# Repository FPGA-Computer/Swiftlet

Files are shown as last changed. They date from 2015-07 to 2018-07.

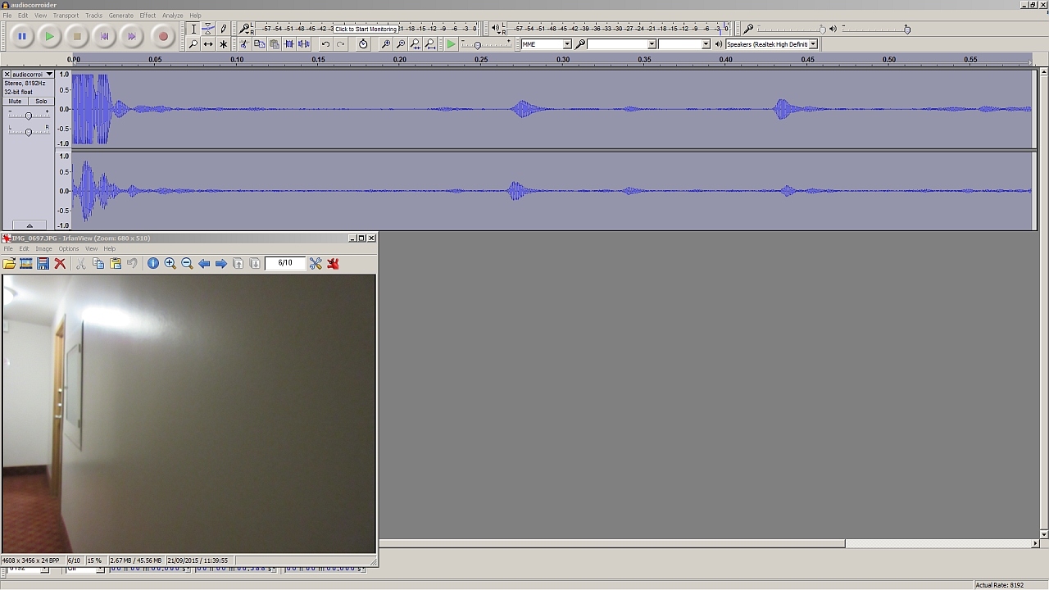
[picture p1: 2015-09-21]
Sonar Samples/corridor1.jpg

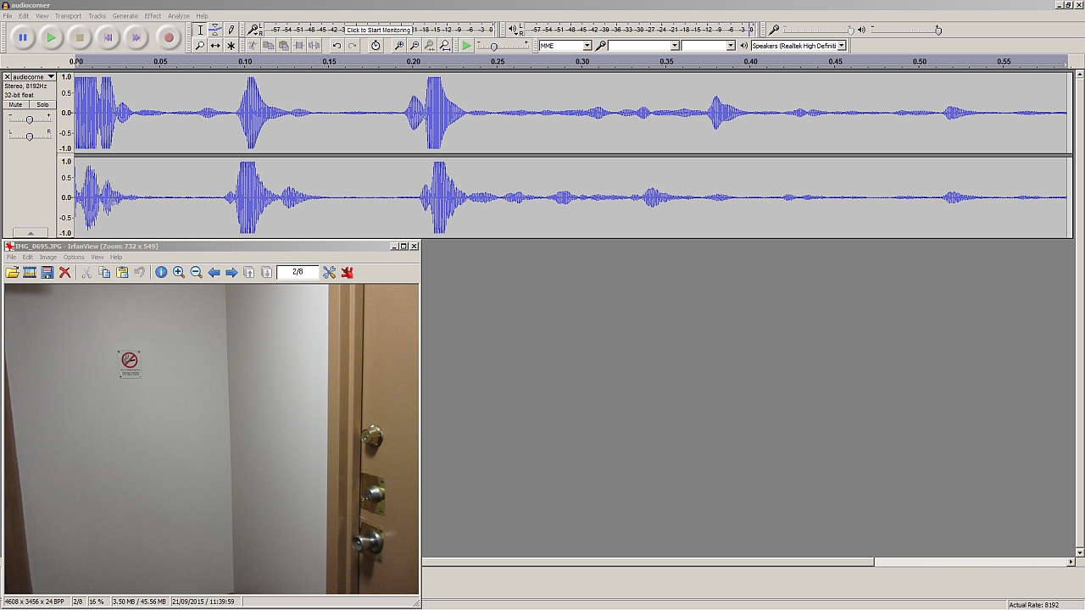
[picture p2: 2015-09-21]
Sonar Samples/Corner.jpg

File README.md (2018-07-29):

This is a Personal Sonar System or the Visually Impaired Person for HaD 2015 Contest Entry.

Ver 0.0 Rel 0/	
Initial PCB release - first layout/non-tested

Ver 0.0 Rel 0.1/	
Initial PCB release - bugs fixed (so far) against Rel 0.0

  Eagle PCB/ Eagle CAD files
  Sketch3D/  Sketch3D model
  LTSpice/   Linear Tech Spice Simulation analog file

Hackaday project page is at 
https://hw-by-design.blogspot.com/2018/07/project-swiftlet-sonar-for-visually.html

This work is licensed under a Creative Commons Attribution-
NonCommercial-ShareAlike 4.0 International License.

The full detail of this license is available at: 
http://creativecommons.org/licenses/by-nc-sa/4.0/

Please contact me via hackaday.io for commercial inquiries.

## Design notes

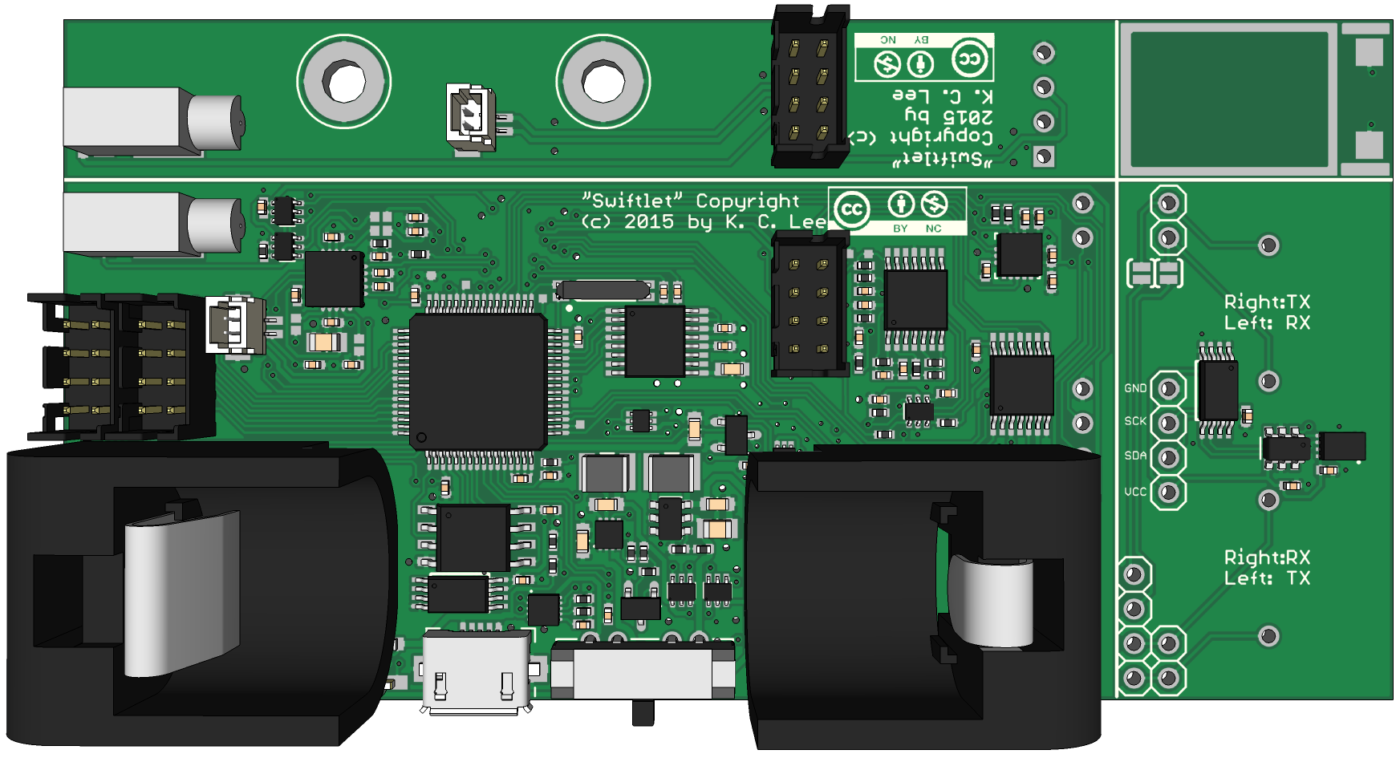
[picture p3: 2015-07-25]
Ver 0.0 Rel 0/Sketch3D/pcb-panel-top.png

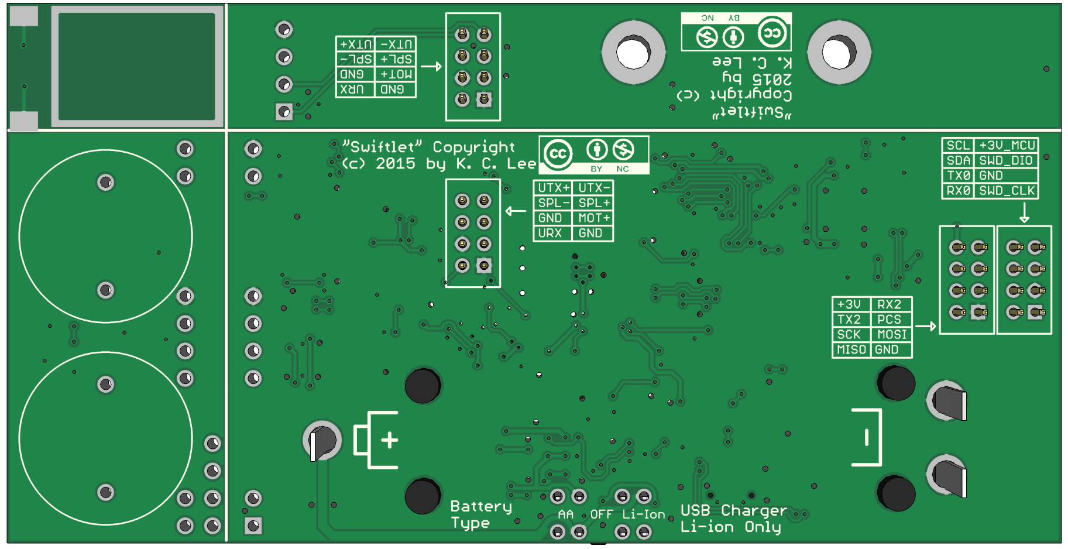
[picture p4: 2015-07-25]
Ver 0.0 Rel 0/Sketch3D/pcb-panel-bot.png

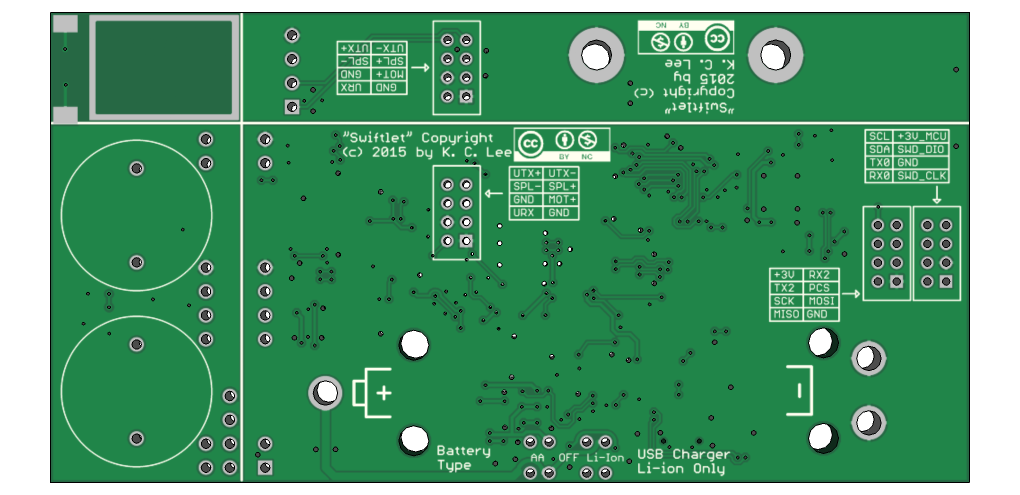
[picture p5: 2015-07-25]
Ver 0.0 Rel 0/Eagle PCB/''Swiftlet'' Sonar for the Visually Impaired Ver 0.0 Rel 0 - Bare PCB Bot.png

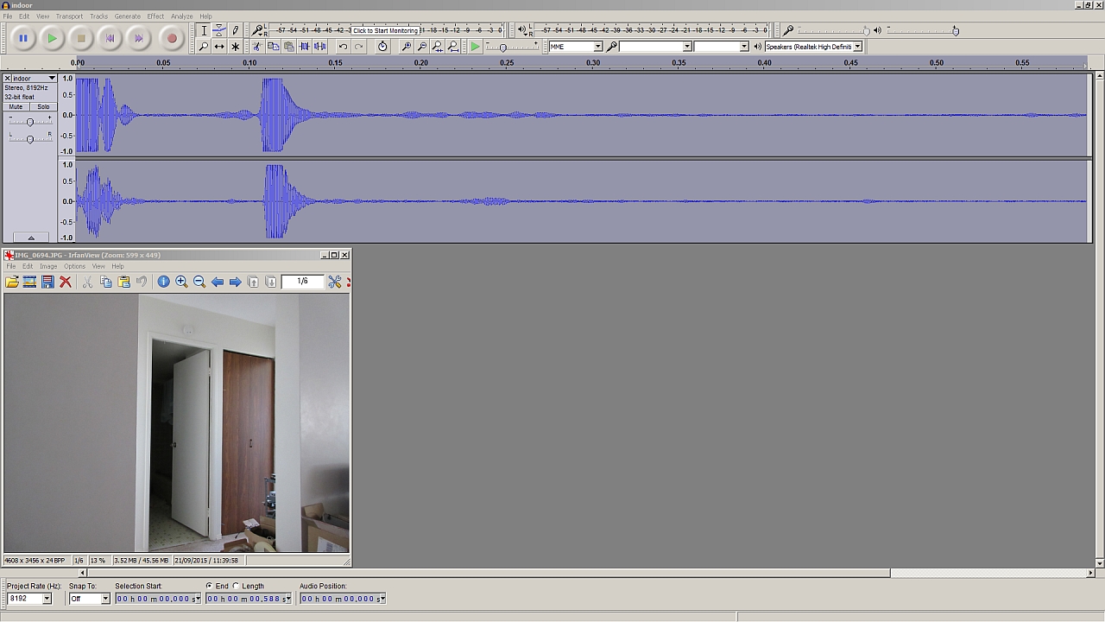
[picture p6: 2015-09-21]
Sonar Samples/indoor.jpg

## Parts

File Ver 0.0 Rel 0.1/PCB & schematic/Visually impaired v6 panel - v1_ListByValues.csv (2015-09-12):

Qty | Value | Part Num | Package | Parts
2 |  | * | 1X02 | J7, J8
2 |  | * | 1X04R | J6, J9
2 |  | * | SJ_2S-NO | SJ1, SJ2
1 |  | DX: SKU134132 | USB-AB-MICRO-SMD_V03_SF | J1
21 | 0.1uF | STOCK: DK 587-1227-1-ND | CAPC1005X60N | C3, C5, C6, C7, C9, C11, C16, C24, C31, C34, C35, C36, C38, C39, C42, C43, C44, C46, C48, C49, C50
1 | 0R | DK: 311-0.0JRCT-ND | RESC1005X40AN | R14
2 | 1K | DK: 311-1.00KLRCT-ND | RESC1005X40AN | R3, R24
1 | 1K5 | DK: 311-1.50KLRCT-ND | RESC1005X40AN | R21
2 | 1M | DK: 311-1.00MLRCT-ND | RESC1005X40AN | R7, R11
5 | 1nF | DK: 490-6349-1-ND | CAPC1005X60N | C12, C13, C18, C19, C20
9 | 1uF | DK: 490-10435-1-ND | CAPC1005X60N | C2, C22, C23, C27, C28, C29, C30, C37, C47
1 | 1uF | STOCK: 1UF/10V 20% TDK | CAPC1608X92N | C4
1 | 2N7002 | STOCK | SOT95P280X135-3N | Q3
2 | 2RB18Z1BS | ALIEXPRESS | 2RB18Z1BS | M1, M2
2 | 3.16K | DK: 1276-4063-1-ND | RESC1005X40AN | R5, R22
5 | 4.7uF | DK: 1276-2087-1-ND | CAPC1608X92N | C1, C10, C14, C15, C45
1 | 6.65K | DK: 1276-4097-1-ND | RESC1005X40AN | R6
1 | 9HT7-32.768KDZF-T | DK: 887-1860-1-ND | 9HT7 | Y1
8 | 10K | DK: 311-10.0KLRCT-ND | RESC1005X40AN | R1, R2, R15, R19, R23, R25, R26, R27
4 | 10nF | DK: 490-1312-1-ND | CAPC1005X60N | C17, C21, C25, C51
2 | 10uF | DK: 490-10470-1-ND | CAP2012X70N | C8, C26
2 | 22K | DK: 311-22.0KLRCT-ND | RESC1005X40AN | R17, R18
1 | 22R | DK: 311-22.0LRCT-ND | RESC1005X40AN | R20
1 | 23LC512-I/ST | DK: 23LC512-I/ST-ND | TSSOP8 | U14
1 | 74LVC08A | DK: 296-1221-1-ND | TSSOP14 | U10
2 | 220K | DK: 311-220KLRCT-ND | RESC1005X40AN | R10, R16
4 | 220pF | DK: 1276-1531-1-ND | CAPC1005X60N | C32, C33, C40, C41
1 | 402K | DK: 1276-4254-1-ND | RESC1005X40AN | R12
2 | 562K | DK: 1276-4268-1-ND | RESC1005X40AN | R8, R9
1 | 665K | DK: 1276-4275-1-ND | RESC1005X40AN | R13
1 | 976K | DK: 1276-4289-1-ND | RESC1005X40AN | R4
1 | 1204-SIDE-DUAL-AG | STOCK | LED_1204 | D1
1 | 2403-260-00001-GRILL | * | 24030269-00001-GRILL | GRILL1
1 | 2403-260-00001TOP | * | 2403-269-00001 | SPK1
1 | AAT2120 | DK: 863-1527-1-ND | STDFN22-8 | U6
1 | AAT3693 | DK: 863-1512-1-ND | TDFN-10 | U3
1 | AK4386ET | DK: 974-1010-1-ND | TSSOP16 | U16
1 | AT24C02 | * | TSSOP8 | U19
2 | BM02B-SRSS-TB | * | BM02B-SRSS-TB | J4, J11
1 | CB-AA-PC-NEG | DK: CB-AA-PC-NEG-ND | CB-AA-PC-NEG | P2
1 | CB-AA-PC-POS | DK: CB-AA-PC-POS-ND | CB-AA-PC-POS | P1
2 | CBC3225T4R7MR | DK: 587-1624-1-ND | INDC3225X135N | L1, L2
2 | CC100% | * | CC-100 | U$1, U$3
1 | CL-SB-23C-11 | DK: 563-1360-ND | SW-JS203011AQN | S1
4 | DF11-8DP-2DSA | DK: H10231-ND | DF11-8DP-2DSA | J2, J3, J5, J10
2 | DMG1023UV | DK: DMG1023UV-7DICT-ND | SOT563 | Q1, Q2
5 | F600R | DK: 553-2374-1-ND | INDC1005X60N | L3, L4, L5, L6, L7
1 | FXOS8700CQR1 | DK: FXOS8700CQR1CT-ND | QFN16_0P5_3X3 | U17
1 | LMV324IPWR | DK: LMV324TSG-13DICT-ND | TSSOP14 | U12
1 | MCP1640T-I/CHY | DK: MCP1640T-I/CHYCT-ND | SOT26 | U4
1 | MCP1700T-3002E/TT | STOCK: MCP1700T-3002E/TTCT-ND | SOT95P280X135-3N | U1
1 | MKL16Z256VLH4 | DK: MKL16Z256VLH4-ND | LQFP64 | U2
2 | MOUNT-PAD-ROUND3.2 | * | 3,2-PAD | H1, H2
4 | NLAS4157 | DK: NLAS4157DFT2GOSCT-ND | DCK_R-PDSO-G6 | U5, U7, U8, U9
1 | PAM8404KG | DK: PAM8404KGRDICT-ND | QFN4040-20 | U15
1 | S25FL127SABMFI101 | STOCK: DK 1274-1045-ND | S0C008 | U13
1 | SE97BTP | * | SOT1069-2 | U18
1 | TC7SB3157CFU | DK: TC7SB3157CFULFCT-ND | DCK_R-PDSO-G6 | U11
2 | TCT40-16T | * | TCT40-16 | T1, T2
1 | TMP101 | * | SOT26 | U20
2 | TPSTP20SQ | * | TP20SQ | TP3, TP4
6 | TPTP06SQ | * | TP06SQ | TP1, TP2, TP5, TP6, TP7, TP8
1 | ULTRASONIC-ASM-SENSOR-ONLY | * | ULTRASONIC-SENSOR-ONLY | A2
1 | ULTRASONIC_TEMP | * | ULTRASONIC_ASM | A1

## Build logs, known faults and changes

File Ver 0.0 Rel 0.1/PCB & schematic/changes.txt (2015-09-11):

R7, R9, R10, C12, C13 : voltage sensing 
- R value changes to account for ARM input leakage
- C value changes for lower time constant

Opamp U12: A, B, D
- fixing the swap in Non-inverting & inverting inputs.

slightly increase separation of the battery holder.  
Not happy with this part.

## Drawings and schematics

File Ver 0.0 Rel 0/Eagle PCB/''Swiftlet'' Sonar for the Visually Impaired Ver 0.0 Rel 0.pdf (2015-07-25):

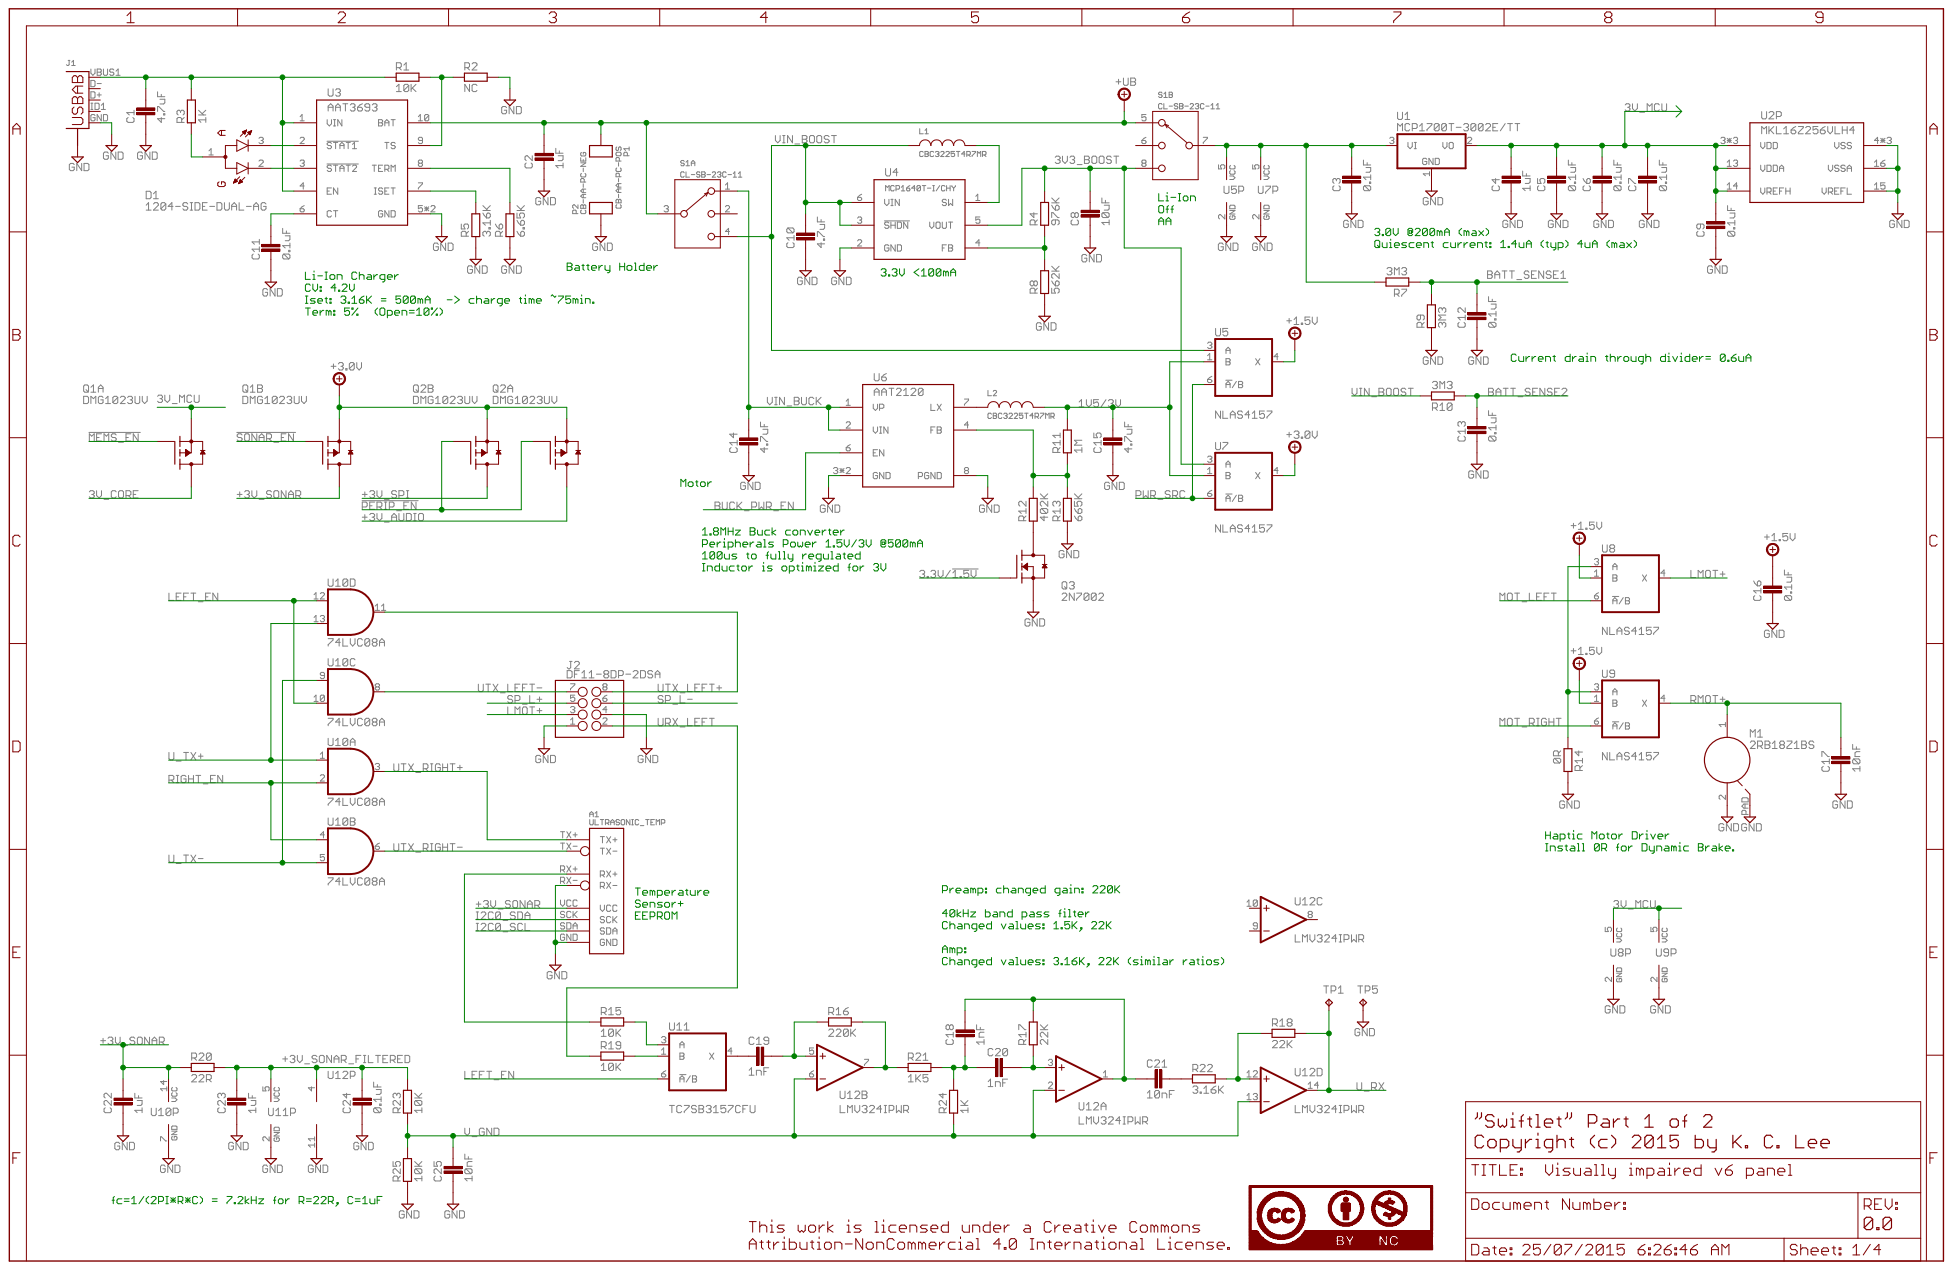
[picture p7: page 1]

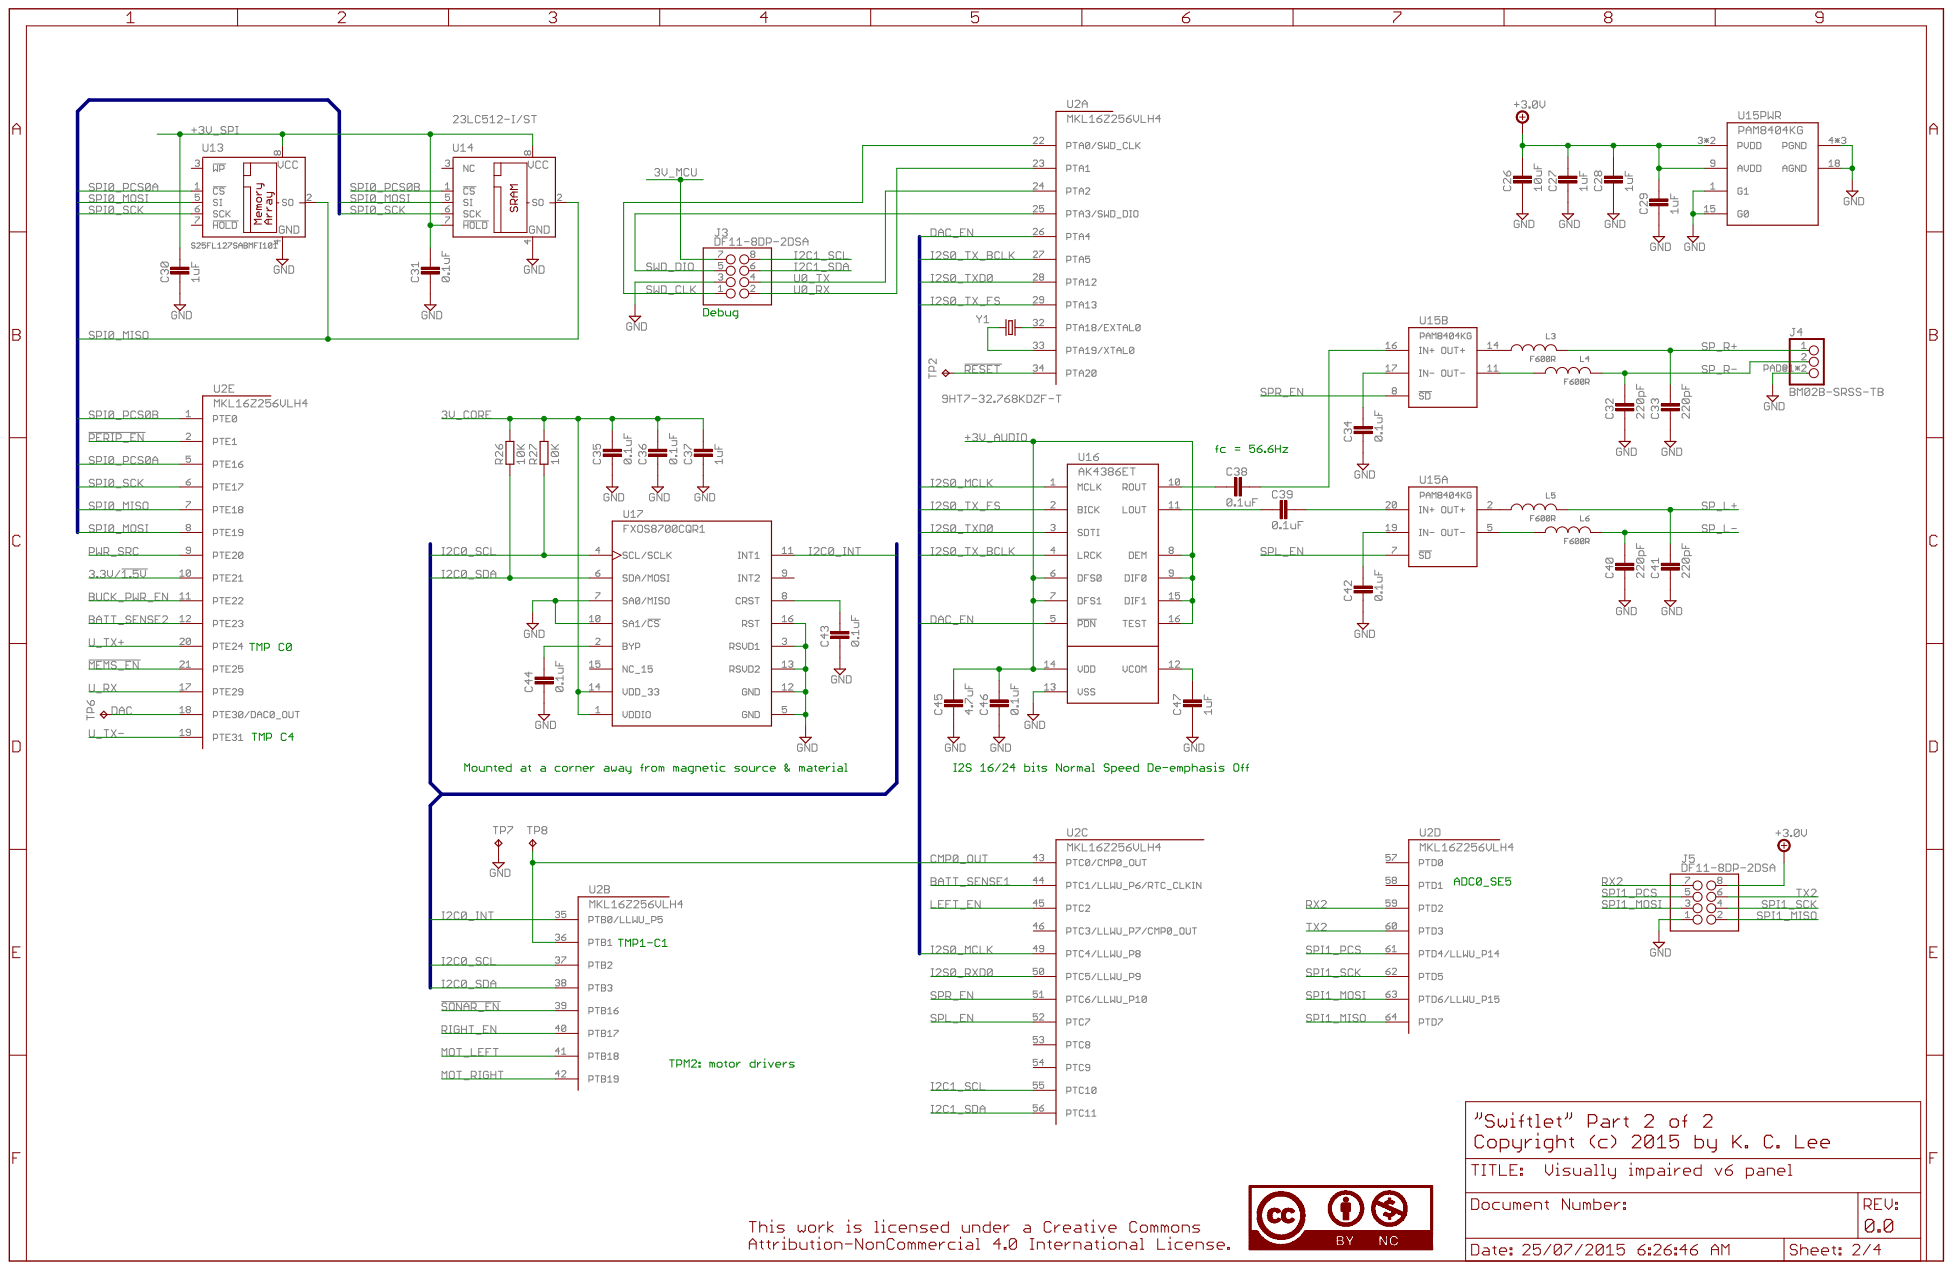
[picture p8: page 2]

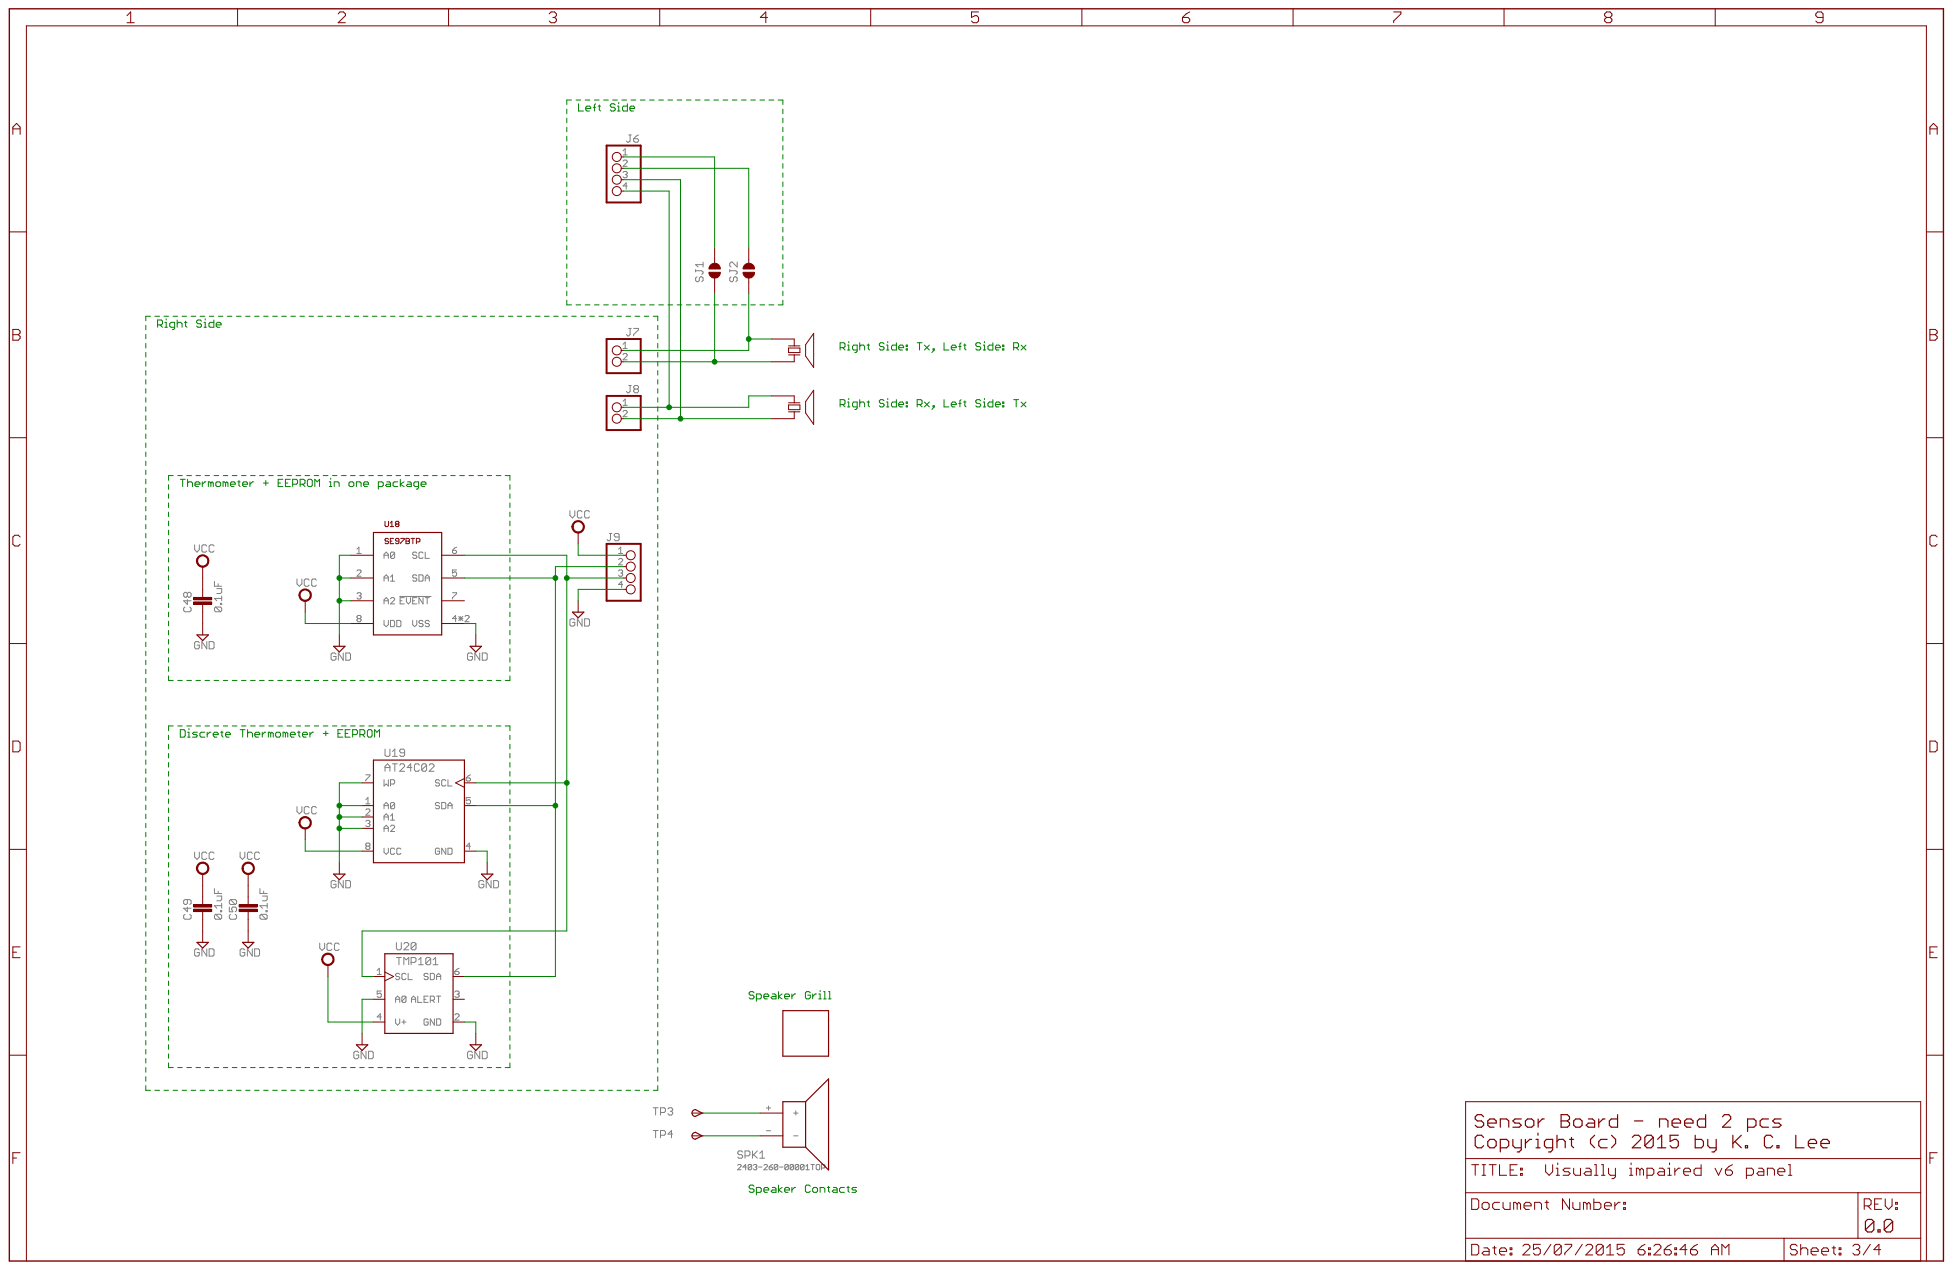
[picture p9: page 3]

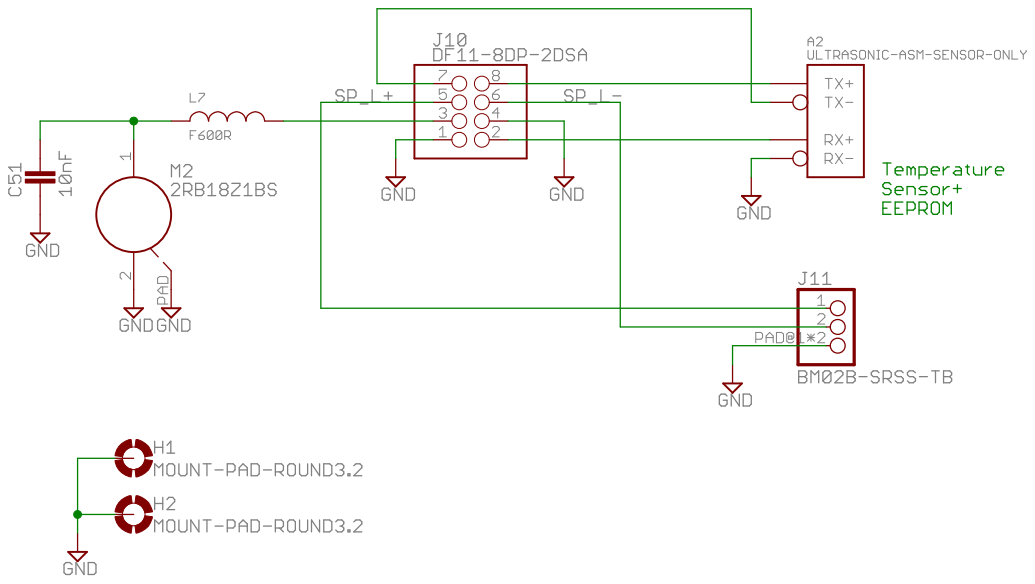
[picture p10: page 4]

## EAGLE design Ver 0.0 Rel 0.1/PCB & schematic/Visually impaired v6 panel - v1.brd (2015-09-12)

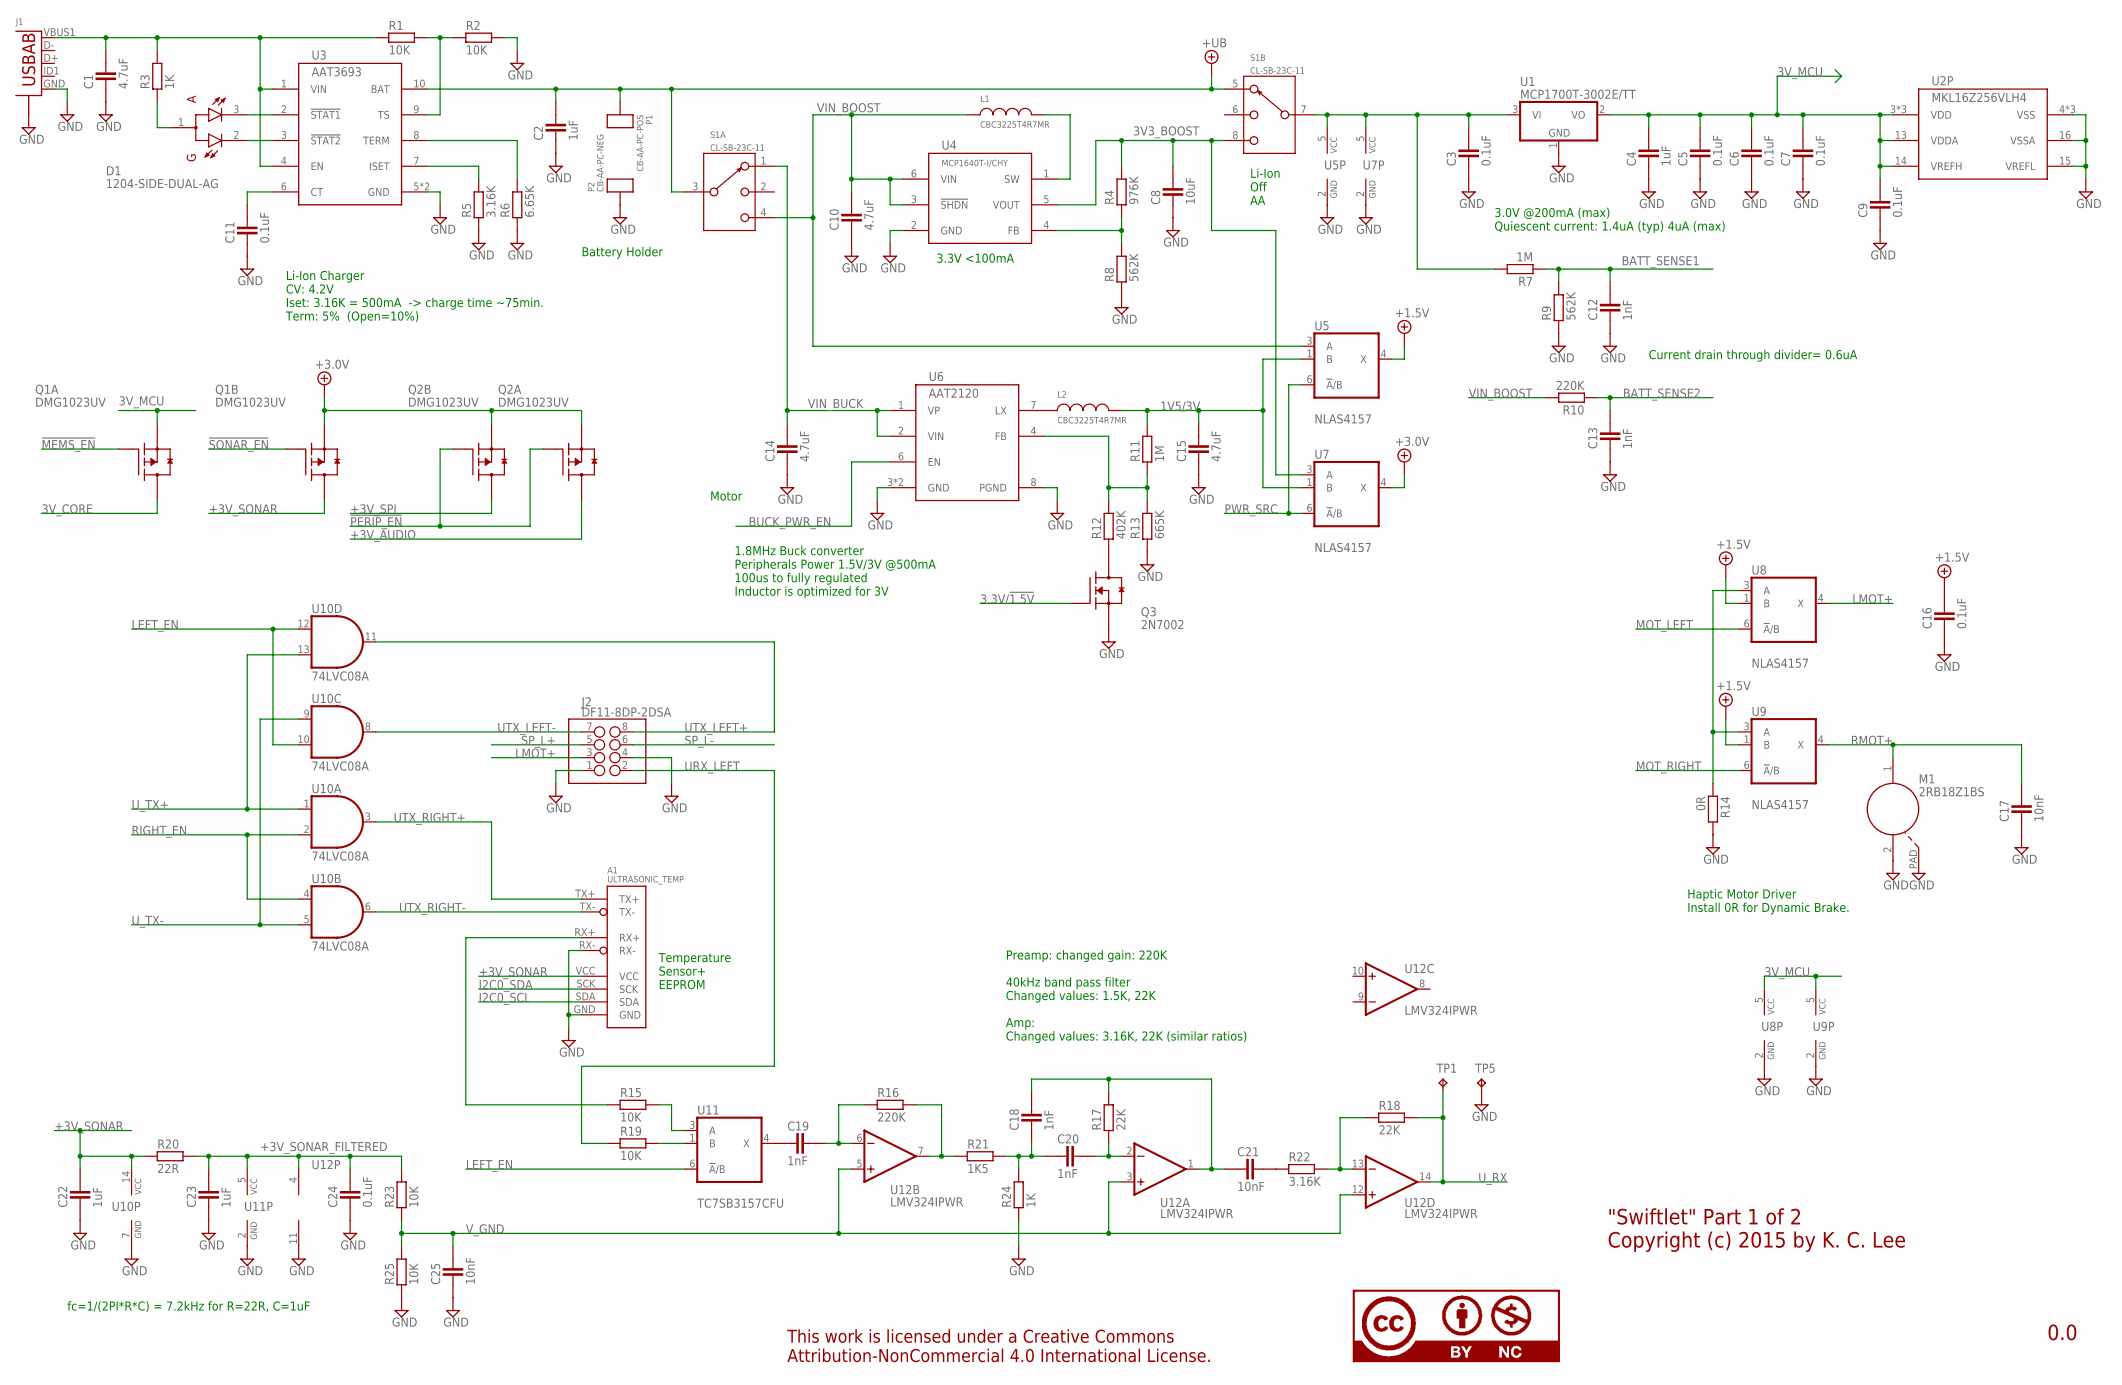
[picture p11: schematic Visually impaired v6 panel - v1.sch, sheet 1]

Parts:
A1: ULTRASONIC_TEMP; ULTRASONIC_ASM; PARTNO *
C1, C10, C14, C15: 4.7uF; CAPC1608X92N; PARTNO DK: 1276-2087-1-ND
C2, C22, C23: 1uF; CAPC1005X60N; PARTNO DK: 490-10435-1-ND
C3, C5, C6, C7, C9, C11, C16, C24: 0.1uF; CAPC1005X60N; PARTNO STOCK: DK 587-1227-1-ND
C4: 1uF; CAPC1608X92N; PARTNO STOCK: 1UF/10V 20% TDK
C8: 10uF; CAP2012X70N; PARTNO DK: 490-10470-1-ND
C12, C13, C18, C19, C20: 1nF; CAPC1005X60N; PARTNO DK: 490-6349-1-ND
C17, C21, C25: 10nF; CAPC1005X60N; PARTNO DK: 490-1312-1-ND
D1: 1204-SIDE-DUAL-AG; LED_1204; PARTNO STOCK
J1: USB-ABBG; USB-AB-MICRO-SMD_V03_SF; PARTNO DX: SKU134132
J2: DF11-8DP-2DSA; PARTNO DK: H10231-ND
L1, L2: CBC3225T4R7MR; INDC3225X135N; PARTNO DK: 587-1624-1-ND
M1: 2RB18Z1BS; PARTNO ALIEXPRESS
P1: CB-AA-PC-POS; PARTNO DK: CB-AA-PC-POS-ND
P2: CB-AA-PC-NEG; PARTNO DK: CB-AA-PC-NEG-ND
Q1, Q2: DMG1023UV; SOT563; PARTNO DK: DMG1023UV-7DICT-ND
Q3: 2N7002; SOT95P280X135-3N; PARTNO STOCK
R1, R2, R15, R19, R23, R25: 10K; RESC1005X40AN; PARTNO DK: 311-10.0KLRCT-ND
R3, R24: 1K; RESC1005X40AN; PARTNO DK: 311-1.00KLRCT-ND
R4: 976K; RESC1005X40AN; PARTNO DK: 1276-4289-1-ND
R5, R22: 3.16K; RESC1005X40AN; PARTNO DK: 1276-4063-1-ND
R6: 6.65K; RESC1005X40AN; PARTNO DK: 1276-4097-1-ND
R7, R11: 1M; RESC1005X40AN; PARTNO DK: 311-1.00MLRCT-ND
R8, R9: 562K; RESC1005X40AN; PARTNO DK: 1276-4268-1-ND
R10, R16: 220K; RESC1005X40AN; PARTNO DK: 311-220KLRCT-ND
R12: 402K; RESC1005X40AN; PARTNO DK: 1276-4254-1-ND
R13: 665K; RESC1005X40AN; PARTNO DK: 1276-4275-1-ND
R14: 0R; RESC1005X40AN; PARTNO DK: 311-0.0JRCT-ND
R17, R18: 22K; RESC1005X40AN; PARTNO DK: 311-22.0KLRCT-ND
R20: 22R; RESC1005X40AN; PARTNO DK: 311-22.0LRCT-ND
R21: 1K5; RESC1005X40AN; PARTNO DK: 311-1.50KLRCT-ND
S1: CL-SB-23C-11; SW-JS203011AQN; PARTNO DK: 563-1360-ND
TP1, TP5: TPTP06SQ; TP06SQ; PARTNO *
U1: MCP1700T-3002E/TT; SOT95P280X135-3N; PARTNO STOCK: MCP1700T-3002E/TTCT-ND
U2: MKL16Z256VLH4; LQFP64; PARTNO DK: MKL16Z256VLH4-ND
U3: AAT3693; TDFN-10; PARTNO DK: 863-1512-1-ND
U4: MCP1640T-I/CHY; SOT26; PARTNO DK: MCP1640T-I/CHYCT-ND
U5, U7, U8, U9: NLAS4157; DCK_R-PDSO-G6; PARTNO DK: NLAS4157DFT2GOSCT-ND
U6: AAT2120; STDFN22-8; PARTNO DK: 863-1527-1-ND
U10: 74LVC08A; TSSOP14; PARTNO DK: 296-1221-1-ND
U11: TC7SB3157CFU; DCK_R-PDSO-G6; PARTNO DK: TC7SB3157CFULFCT-ND
U12: LMV324IPWR; TSSOP14; PARTNO DK: LMV324TSG-13DICT-ND
U$1: CC100%; CC-100; PARTNO *

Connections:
1V5/3V: C15.2, L2.2, R11.2, U5.1 (B), U7.1 (B)
3.3V/!1.5V: Q3.1 (G); also elsewhere on the board
3V3_BOOST: C8.2, R4.2, S1.8 (3), U4.5 (VOUT), U7.3 (A)
3V_CORE: Q1.P$6 (D); also elsewhere on the board
3V_MCU: C4.2, C5.2, C6.2, C7.2, C9.2, Q1.P$1 (S), U1.2 (VO), U2.3 (VDD), U2.13 (VDDA), U2.14 (VREFH), U2.30 (VDD), U2.48 (VDD), U8.5 (VCC), U9.5 (VCC); also elsewhere on the board
!MEMS_EN: Q1.P$2 (G); also elsewhere on the board
!PERIP_EN: Q2.P$2 (G), Q2.P$5 (G); also elsewhere on the board
!SONAR_EN: Q1.P$5 (G); also elsewhere on the board
+1.5V: C16.2, U5.4 (X), U8.1 (B), U9.1 (B)
+3.0V: Q1.P$4 (S), Q2.P$1 (S), Q2.P$4 (S), U7.4 (X); also elsewhere on the board
+3V_AUDIO: Q2.P$6 (D); also elsewhere on the board
+3V_SONAR: A1.VCC, C22.2, Q1.P$3 (D), R20.1, U10.14 (VCC)
+3V_SONAR_FILTERED: C23.2, C24.2, R20.2, R23.2, U11.5 (VCC), U12.4 (V+)
+3V_SPI: Q2.P$3 (D); also elsewhere on the board
+UB: C2.2, P1.1, S1.3 (S), S1.5 (1), U3.10 (BAT)
BATT_SENSE1: C12.2, R7.1, R9.2; also elsewhere on the board
BATT_SENSE2: C13.2, R10.1; also elsewhere on the board
BUCK_PWR_EN: U6.6 (EN); also elsewhere on the board
GND: A1.GND, A1.RX-, C1.1, C2.1, C3.1, C4.1, C5.1, C6.1, C7.1, C8.1, C9.1, C10.1, C11.1, C12.1, C13.1, C14.1, C15.1, C16.1, C17.1, C22.1, C23.1, C24.1, C25.1, J1.GND, J1.S1 (S), J1.S2 (S), J1.S3 (S), J1.S4 (S), J2.1, J2.4, M1.2, M1.PAD, P2.1, P2.2, Q3.2 (S), R2.2, R5.1, R6.1, R8.1, R9.1, R13.1, R14.2, R24.1, R25.1, TP5.TP, U1.1 (GND), U2.4 (VSS), U2.15 (VREFL), U2.16 (VSSA), U2.31 (VSS), U2.47 (VSS), U3.5 (GND), U3.EP (GND), U4.2 (GND), U5.2 (GND), U6.3 (GND), U6.8 (PGND), U6.PAD (GND), U7.2 (GND), U8.2 (GND), U9.2 (GND), U10.7 (GND), U11.2 (GND), U12.11 (V-); also elsewhere on the board
I2C0_SCL: A1.SDA; also elsewhere on the board
I2C0_SDA: A1.SCK; also elsewhere on the board
LEFT_EN: U10.10 (I1), U10.12 (I0), U11.6 (!A!/B); also elsewhere on the board
LMOT+: J2.3, U8.4 (X)
MOT_LEFT: U8.6 (!A!/B); also elsewhere on the board
MOT_RIGHT: U9.6 (!A!/B); also elsewhere on the board
unnamed: A1.RX+, R15.1
unnamed: R14.1, U8.3 (A), U9.3 (A)
unnamed: L1.2, U4.1 (SW)
unnamed: C11.2, U3.6 (CT)
unnamed: R5.2, U3.7 (ISET)
unnamed: R6.2, U3.8 (TERM)
unnamed: D1.1 (A), R3.1
unnamed: D1.3 (C1), U3.2 (!STAT1)
unnamed: D1.2 (C2), U3.3 (!STAT2)
unnamed: C1.2, J1.VBUS1 (VBUS), R1.1, R3.2, U3.1 (VIN), U3.4 (EN)
unnamed: R1.2, R2.1, U3.9 (TS)
unnamed: C21.2, R22.1
unnamed: R19.2, U11.1 (B)
unnamed: R18.1, R22.2, U12.13 (-IN)
unnamed: C19.2, R16.1, U12.6 (-IN)
unnamed: R16.2, R21.1, U12.7 (OUT)
unnamed: C18.1, C20.1, R21.2, R24.2
unnamed: C20.2, R17.1, U12.2 (-IN)
unnamed: R15.2, U11.3 (A)
unnamed: C19.1, U11.4 (X)
unnamed: R4.1, R8.2, U4.4 (FB)
unnamed: L2.1, U6.7 (LX)
unnamed: R11.1, R12.2, R13.2, U6.4 (FB)
unnamed: Q3.3 (D), R12.1
PWR_SRC: U5.6 (!A!/B), U7.6 (!A!/B); also elsewhere on the board
RIGHT_EN: U10.2 (I1), U10.4 (I0); also elsewhere on the board
RMOT+: C17.2, M1.1, U9.4 (X)
SP_L+: J2.5; also elsewhere on the board
SP_L-: J2.6; also elsewhere on the board
URX_LEFT: J2.2, R19.1
UTX_LEFT+: J2.8, U10.11 (O)
UTX_LEFT-: J2.7, U10.8 (O)
UTX_RIGHT+: A1.TX+, U10.3 (O)
UTX_RIGHT-: A1.TX-, U10.6 (O)
U_RX: R18.2, TP1.TP, U12.14 (OUT); also elsewhere on the board
U_RX__: C18.2, C21.1, R17.2, U12.1 (OUT)
U_TX+: U10.1 (I0), U10.13 (I1); also elsewhere on the board
U_TX-: U10.5 (I1), U10.9 (I0); also elsewhere on the board
VIN_BOOST: C10.2, L1.1, R10.2, S1.4 (3), U4.3 (!SHDN), U4.6 (VIN), U5.3 (A)
VIN_BUCK: C14.2, S1.1, U6.1 (VP), U6.2 (VIN)
VIN_MCU: C3.2, R7.2, S1.7 (S), U1.3 (VI), U5.5 (VCC), U7.5 (VCC)
V_GND: C25.2, R23.1, R25.2, U12.3 (+IN), U12.5 (+IN), U12.12 (+IN)

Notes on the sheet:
Li-Ion Off AA
3.3V <100mA
Li-Ion Charger CV: 4.2V Iset: 3.16K = 500mA -> charge time ~75min. Term: 5% (Open=10%)
3.0V @200mA (max) Quiescent current: 1.4uA (typ) 4uA (max)
Motor
Battery Holder
Preamp: changed gain: 220K 40kHz band pass filter Changed values: 1.5K, 22K Amp: Changed values: 3.16K, 22K (similar ratios)
1.8MHz Buck converter Peripherals Power 1.5V/3V @500mA 100us to fully regulated Inductor is optimized for 3V
Temperature Sensor+ EEPROM
Haptic Motor Driver Install 0R for Dynamic Brake.
fc=1/(2PI*R*C) = 7.2kHz for R=22R, C=1uF
"Swiftlet" Part 1 of 2 Copyright (c) 2015 by K. C. Lee
0.0
Current drain through divider= 0.6uA

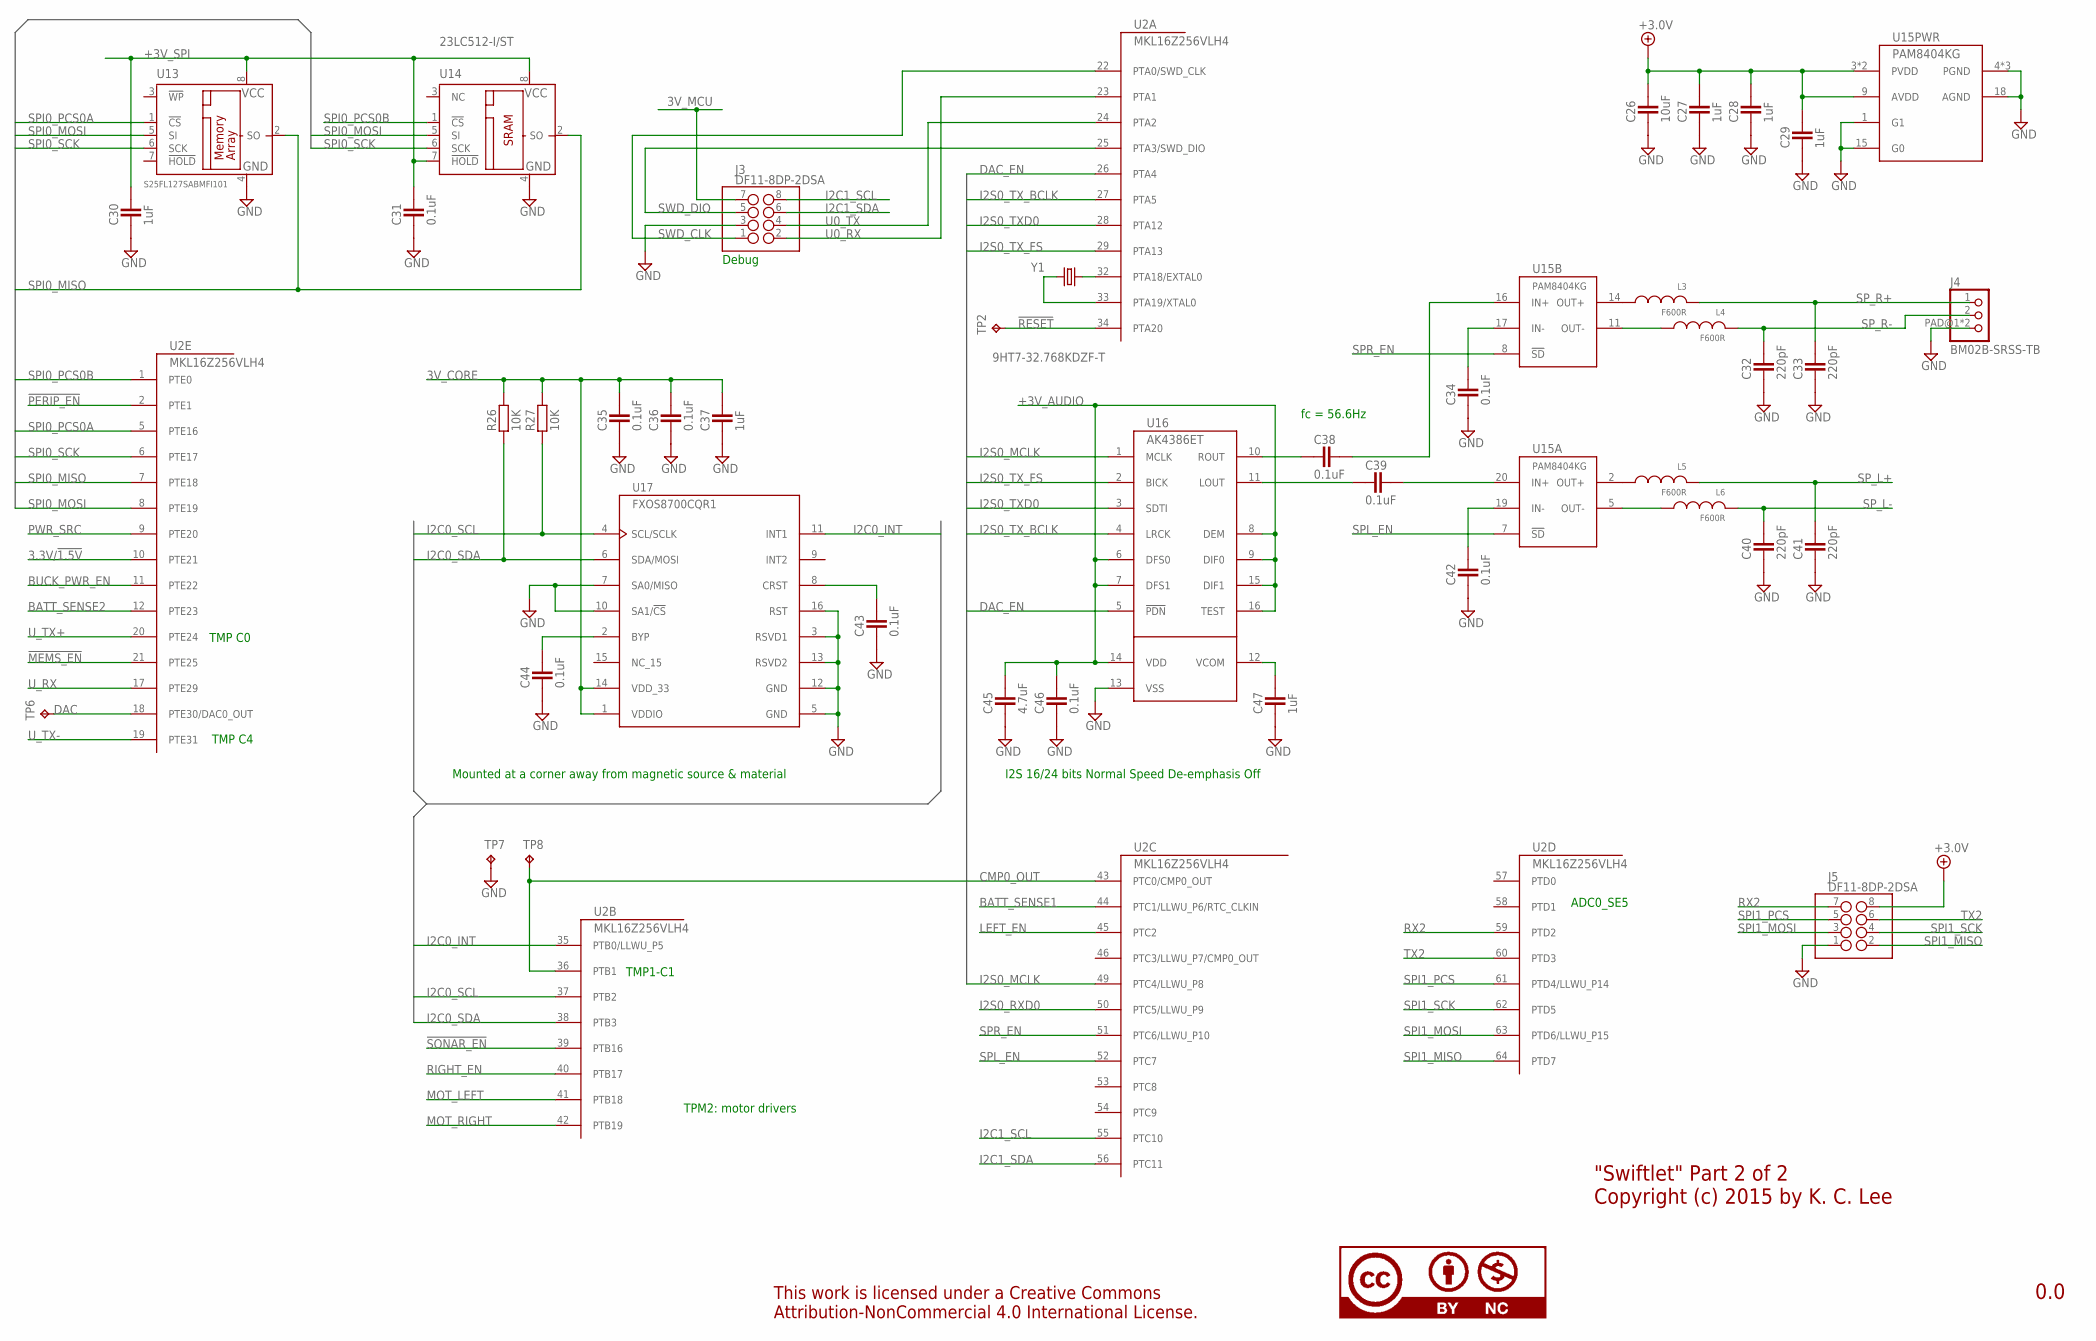
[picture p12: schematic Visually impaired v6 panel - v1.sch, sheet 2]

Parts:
C26: 10uF; CAP2012X70N; PARTNO DK: 490-10470-1-ND
C27, C28, C29, C30, C37, C47: 1uF; CAPC1005X60N; PARTNO DK: 490-10435-1-ND
C31, C34, C35, C36, C38, C39, C42, C43, C44, C46: 0.1uF; CAPC1005X60N; PARTNO STOCK: DK 587-1227-1-ND
C32, C33, C40, C41: 220pF; CAPC1005X60N; PARTNO DK: 1276-1531-1-ND
C45: 4.7uF; CAPC1608X92N; PARTNO DK: 1276-2087-1-ND
J3, J5: DF11-8DP-2DSA; PARTNO DK: H10231-ND
J4: BM02B-SRSS-TB; PARTNO *
L3, L4, L5, L6: F600R; INDC1005X60N; PARTNO DK: 553-2374-1-ND
R26, R27: 10K; RESC1005X40AN; PARTNO DK: 311-10.0KLRCT-ND
TP2, TP6, TP7, TP8: TPTP06SQ; TP06SQ; PARTNO *
U2: MKL16Z256VLH4; LQFP64; PARTNO DK: MKL16Z256VLH4-ND
U13: S25FL127SABMFI101; S0C008; PARTNO STOCK: DK 1274-1045-ND
U14: 23LC512-I/ST; TSSOP8; PARTNO DK: 23LC512-I/ST-ND
U15: PAM8404KG; QFN4040-20; PARTNO DK: PAM8404KGRDICT-ND
U16: AK4386ET; TSSOP16; PARTNO DK: 974-1010-1-ND
U17: FXOS8700CQR1; QFN16_0P5_3X3; PARTNO DK: FXOS8700CQR1CT-ND
U$3: CC100%; CC-100; PARTNO *
Y1: 9HT7-32.768KDZF-T; 9HT7; PARTNO DK: 887-1860-1-ND

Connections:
3.3V/!1.5V: U2.10 (PTE21); also elsewhere on the board
3V_CORE: C35.2, C36.2, C37.2, R26.2, R27.2, U17.1 (VDDIO), U17.14 (VDD_33); also elsewhere on the board
3V_MCU: J3.7; also elsewhere on the board
!MEMS_EN: U2.21 (PTE25); also elsewhere on the board
!PERIP_EN: U2.2 (PTE1); also elsewhere on the board
!RESET: TP2.TP, U2.34 (PTA20)
!SONAR_EN: U2.39 (PTB16); also elsewhere on the board
+3.0V: C26.2, C27.2, C28.2, C29.2, J5.8, U15.3 (PVDD), U15.9 (AVDD), U15.13 (PVDD); also elsewhere on the board
+3V_AUDIO: C45.2, C46.2, U16.6 (DFS0), U16.7 (DFS1), U16.8 (DEM), U16.9 (DIF0), U16.14 (VDD), U16.15 (DIF1), U16.16 (TEST); also elsewhere on the board
+3V_SPI: C30.2, C31.2, U13.8 (VCC), U14.7 (!HOLD), U14.8 (VCC); also elsewhere on the board
BATT_SENSE1: U2.44 (PTC1/LLWU_P6/RTC_CLKIN); also elsewhere on the board
BATT_SENSE2: U2.12 (PTE23); also elsewhere on the board
BUCK_PWR_EN: U2.11 (PTE22); also elsewhere on the board
BYP: C44.2, U17.2 (BYP)
CMP0_OUT: TP8.TP, U2.36 (PTB1), U2.43 (PTC0/CMP0_OUT)
CRST: C43.2, U17.8 (CRST)
DAC: TP6.TP, U2.18 (PTE30/DAC0_OUT)
DAC_EN: U2.26 (PTA4), U16.5 (!PDN)
GND: C26.1, C27.1, C28.1, C29.1, C30.1, C31.1, C32.1, C33.1, C34.1, C35.1, C36.1, C37.1, C40.1, C41.1, C42.1, C43.1, C44.1, C45.1, C46.1, C47.1, J3.3, J4.PAD@1 (3), J4.PAD@2 (3), J5.1, TP7.TP, U13.4 (GND), U14.4 (GND), U15.1 (G1), U15.4 (PGND), U15.12 (PGND), U15.15 (G0), U15.18 (AGND), U15.PAD (PGND), U16.13 (VSS), U17.3 (RSVD1), U17.5 (GND), U17.7 (SA0/MISO), U17.10 (SA1/!CS), U17.12 (GND), U17.13 (RSVD2), U17.16 (RST); also elsewhere on the board
I2C0_INT: U2.35 (PTB0/LLWU_P5), U17.11 (INT1)
I2C0_SCL: R27.1, U2.37 (PTB2), U17.4 (SCL/SCLK); also elsewhere on the board
I2C0_SDA: R26.1, U2.38 (PTB3), U17.6 (SDA/MOSI); also elsewhere on the board
I2C1_SCL: J3.8, U2.55 (PTC10)
I2C1_SDA: J3.6, U2.56 (PTC11)
I2S0_MCLK: U2.49 (PTC4/LLWU_P8), U16.1 (MCLK)
I2S0_RXD0: U2.50 (PTC5/LLWU_P9)
I2S0_TXD0: U2.28 (PTA12), U16.3 (SDTI)
I2S0_TX_BCLK: U2.27 (PTA5), U16.4 (LRCK)
I2S0_TX_FS: U2.29 (PTA13), U16.2 (BICK)
LEFT_EN: U2.45 (PTC2); also elsewhere on the board
MOT_LEFT: U2.41 (PTB18); also elsewhere on the board
MOT_RIGHT: U2.42 (PTB19); also elsewhere on the board
unnamed: U2.32 (PTA18/EXTAL0), Y1.1
unnamed: U2.33 (PTA19/XTAL0), Y1.4 (2)
unnamed: C34.2, U15.17 (IN-)
unnamed: C47.2, U16.12 (VCOM)
unnamed: C42.2, U15.19 (IN-)
unnamed: C38.1, U16.10 (ROUT)
unnamed: C38.2, U15.16 (IN+)
unnamed: C39.1, U16.11 (LOUT)
unnamed: C39.2, U15.20 (IN+)
unnamed: L3.2, U15.14 (OUT+)
unnamed: L4.2, U15.11 (OUT-)
unnamed: L5.2, U15.2 (OUT+)
unnamed: L6.2, U15.5 (OUT-)
PWR_SRC: U2.9 (PTE20); also elsewhere on the board
RIGHT_EN: U2.40 (PTB17); also elsewhere on the board
RX2: J5.7, U2.59 (PTD2)
SPI0_MISO: U2.7 (PTE18), U13.2 (SO), U14.2 (SO)
SPI0_MOSI: U2.8 (PTE19), U13.5 (SI), U14.5 (SI)
SPI0_PCS0A: U2.5 (PTE16), U13.1 (!CS)
SPI0_PCS0B: U2.1 (PTE0), U14.1 (!CS)
SPI0_SCK: U2.6 (PTE17), U13.6 (SCK), U14.6 (SCK)
SPI1_MISO: J5.2, U2.64 (PTD7)
SPI1_MOSI: J5.3, U2.63 (PTD6/LLWU_P15)
SPI1_PCS: J5.5, U2.61 (PTD4/LLWU_P14)
SPI1_SCK: J5.4, U2.62 (PTD5)
SPL_EN: U2.52 (PTC7), U15.7 (!SD)
SPR_EN: U2.51 (PTC6/LLWU_P10), U15.8 (!SD)
SP_L+: C41.2, L5.1; also elsewhere on the board
SP_L-: C40.2, L6.1; also elsewhere on the board
SP_R+: C33.2, J4.1, L3.1
SP_R-: C32.2, J4.2, L4.1
SWD_CLK: J3.1, U2.22 (PTA0/SWD_CLK)
SWD_DIO: J3.5, U2.25 (PTA3/SWD_DIO)
TX2: J5.6, U2.60 (PTD3)
U0_RX: J3.2, U2.23 (PTA1)
U0_TX: J3.4, U2.24 (PTA2)
U_RX: U2.17 (PTE29); also elsewhere on the board
U_TX+: U2.20 (PTE24); also elsewhere on the board
U_TX-: U2.19 (PTE31); also elsewhere on the board

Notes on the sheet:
TPM2: motor drivers
ADC0_SE5
I2S 16/24 bits Normal Speed De-emphasis Off
Mounted at a corner away from magnetic source & material
TMP C0
TMP C4
TMP1-C1
Debug
fc = 56.6Hz
"Swiftlet" Part 2 of 2 Copyright (c) 2015 by K. C. Lee
0.0

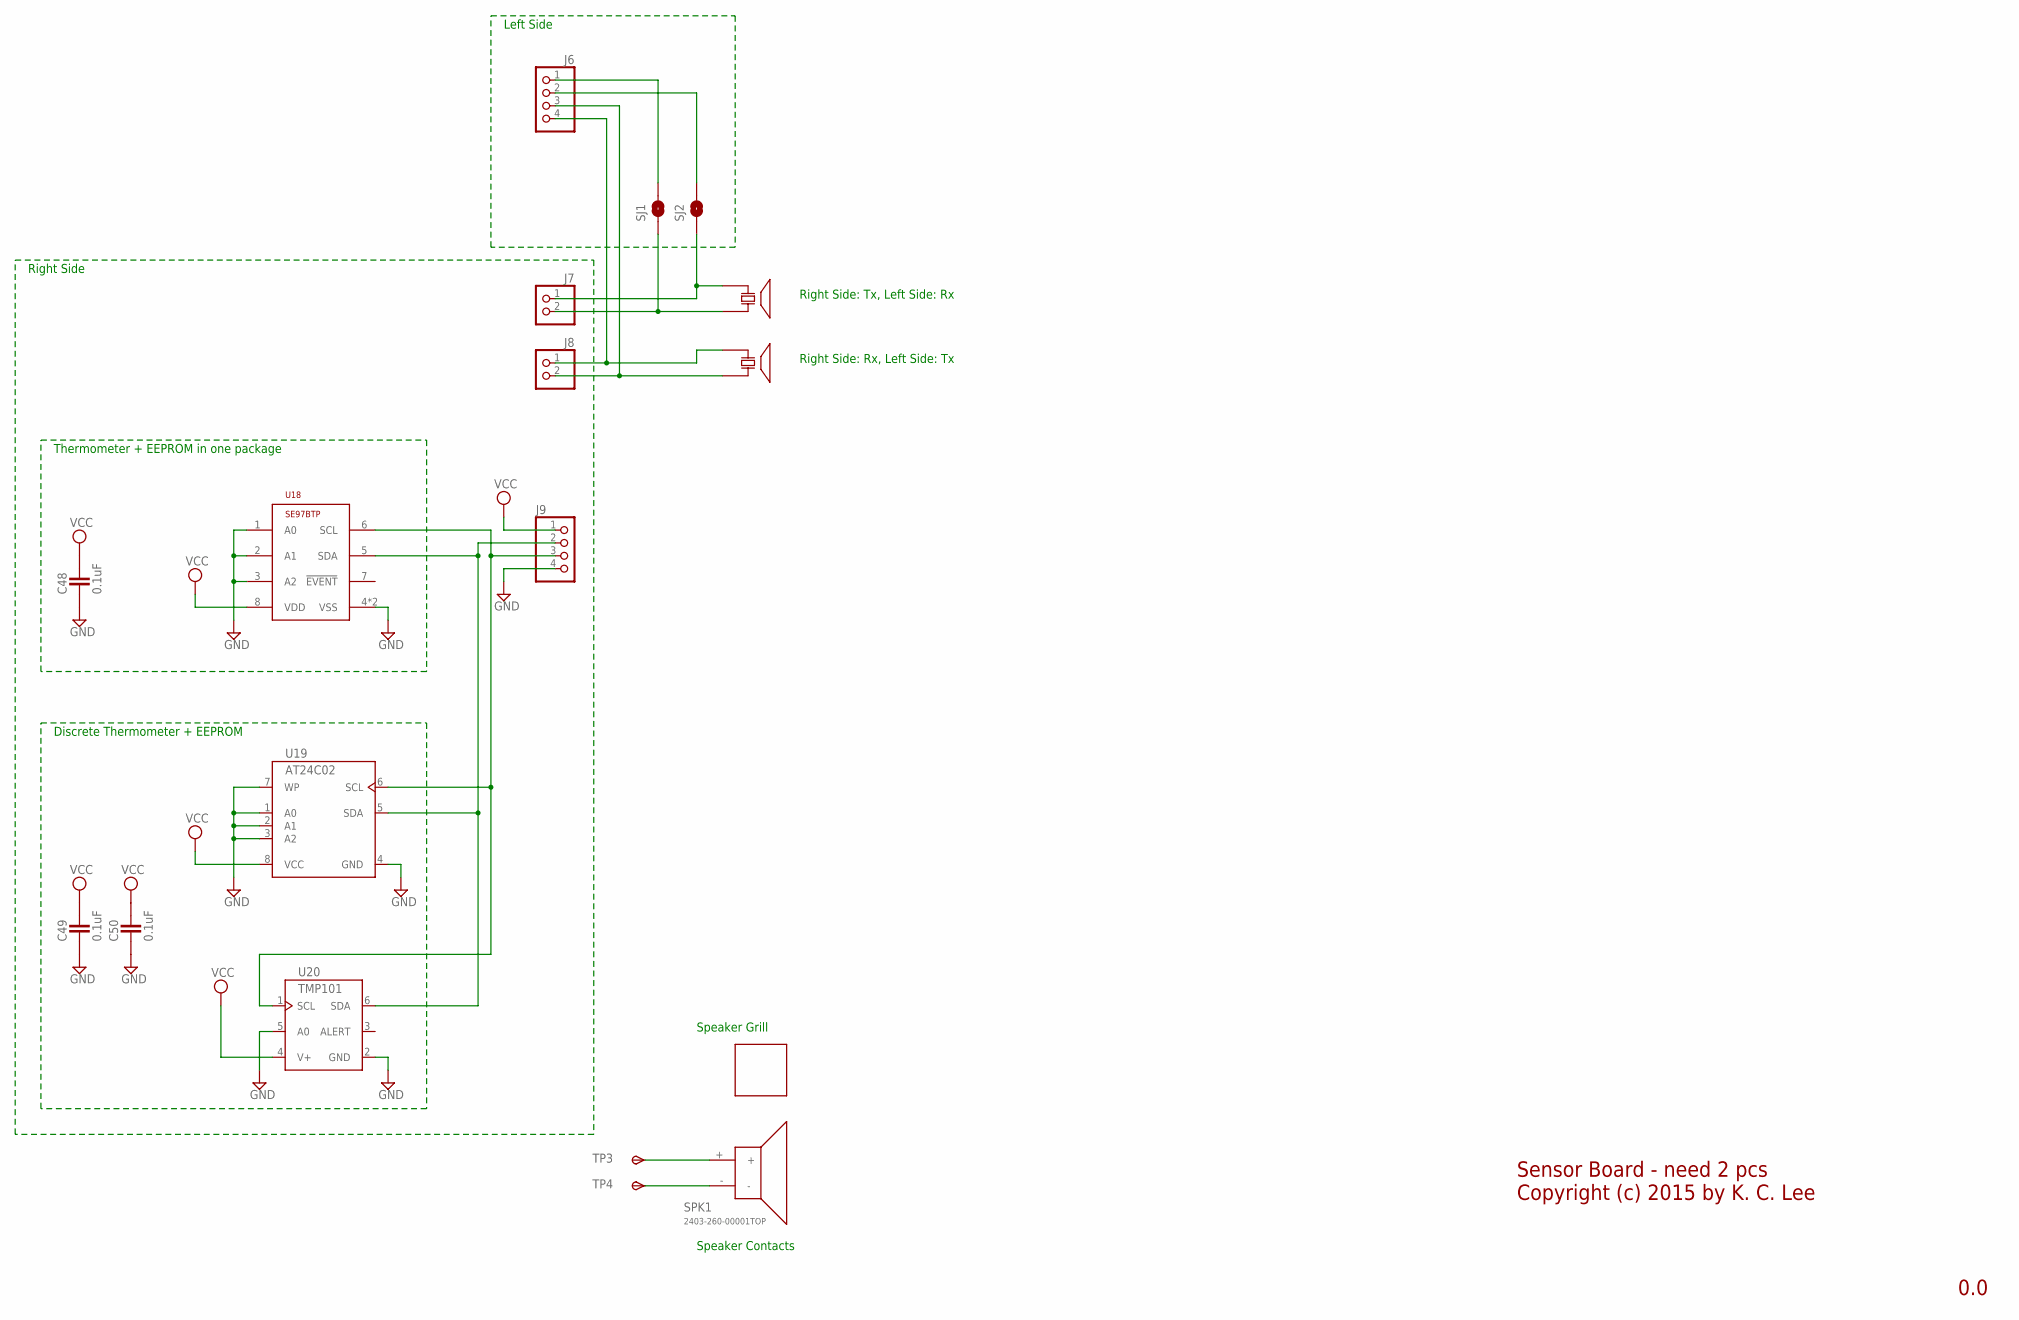
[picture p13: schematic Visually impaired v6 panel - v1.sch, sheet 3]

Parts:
C48, C49, C50: 0.1uF; CAPC1005X60N; PARTNO STOCK: DK 587-1227-1-ND
GRILL1: 2403-260-00001-GRILL; 24030269-00001-GRILL; PARTNO *
J6, J9: PINHD-1X4_2.54_R; 1X04R; PARTNO *
J7, J8: PINHD-1X2_2.54; 1X02; PARTNO *
SJ1, SJ2: SOLDERJUMPERNO; SJ_2S-NO; PARTNO *
SPK1: 2403-260-00001TOP; 2403-269-00001; PARTNO *
T1, T2: TCT40-16T; TCT40-16; PARTNO *
TP3, TP4: TPSTP20SQ; TP20SQ; PARTNO *
U18: SE97BTP; SOT1069-2; PARTNO *
U19: AT24C02; TSSOP8; PARTNO *
U20: TMP101; SOT26; PARTNO *

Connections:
GND: C48.1, C49.1, C50.1, J9.4, U18.1 (A0), U18.2 (A1), U18.3 (A2), U18.4 (VSS), U18.PAD (VSS), U19.1 (A0), U19.2 (A1), U19.3 (A2), U19.4 (GND), U19.7 (WP), U20.2 (GND), U20.5 (A0); also elsewhere on the board
unnamed: J6.2, SJ2.2
unnamed: J7.2, SJ1.1, T1.P$2
unnamed: J9.2, U18.5 (SDA), U19.5 (SDA), U20.6 (SDA)
unnamed: J9.3, U18.6 (SCL), U19.6 (SCL), U20.1 (SCL)
unnamed: J6.4, J8.1, T2.P$1
unnamed: J6.3, J8.2, T2.P$2
unnamed: J6.1, SJ1.2
unnamed: J7.1, SJ2.1, T1.P$1
unnamed: SPK1.+, TP3.TP
unnamed: SPK1.-, TP4.TP
VCC: C48.2, C49.2, C50.2, J9.1, U18.8 (VDD), U19.8 (VCC), U20.4 (V+)

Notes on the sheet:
Thermometer + EEPROM in one package
Discrete Thermometer + EEPROM
Left Side
Right Side
Right Side: Tx, Left Side: Rx
Right Side: Rx, Left Side: Tx
Sensor Board - need 2 pcs Copyright (c) 2015 by K. C. Lee
Speaker Grill
Speaker Contacts
0.0

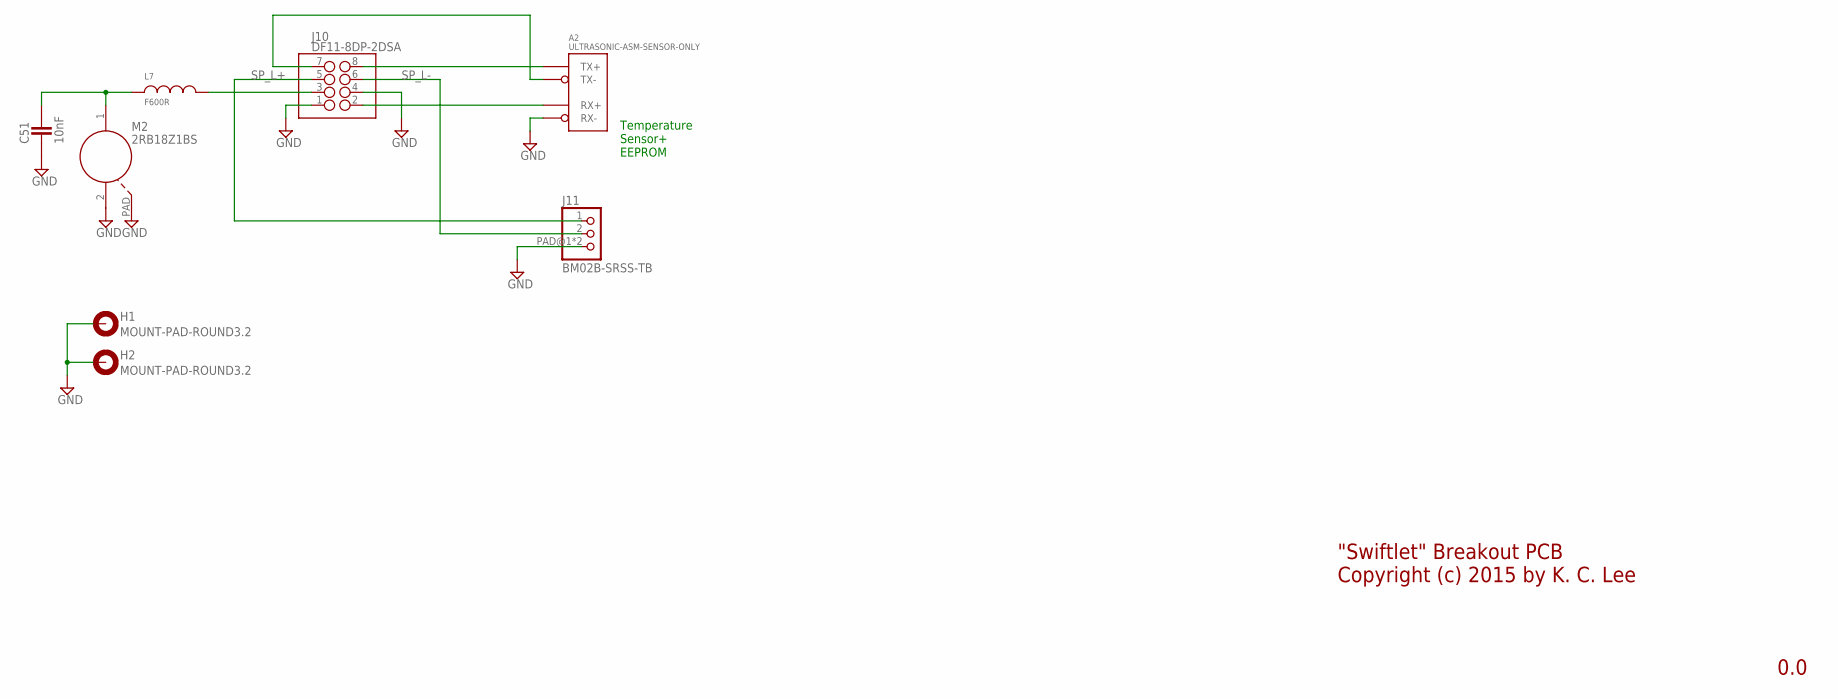
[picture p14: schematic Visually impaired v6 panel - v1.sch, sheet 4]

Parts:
A2: ULTRASONIC-ASM-SENSOR-ONLY; ULTRASONIC-SENSOR-ONLY; PARTNO *
C51: 10nF; CAPC1005X60N; PARTNO DK: 490-1312-1-ND
H1, H2: MOUNT-PAD-ROUND3.2; 3,2-PAD; PARTNO *
J10: DF11-8DP-2DSA; PARTNO DK: H10231-ND
J11: BM02B-SRSS-TB; PARTNO *
L7: F600R; INDC1005X60N; PARTNO DK: 553-2374-1-ND
M2: 2RB18Z1BS; PARTNO ALIEXPRESS

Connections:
GND: A2.TX+ (RX-), C51.1, H1.B3,2, H2.B3,2, J10.1, J10.4, J11.PAD@1 (3), J11.PAD@2 (3), M2.2, M2.PAD; also elsewhere on the board
LMOT+1: C51.2, L7.1, M2.1
unnamed: A2.RX+ (TX-), J10.7
unnamed: A2.TX- (RX+), J10.2
unnamed: J10.3, L7.2
SP_L+: J10.5, J11.1; also elsewhere on the board
SP_L-: J10.6, J11.2; also elsewhere on the board
UTX_RIGHT+1: A2.RX- (TX+), J10.8

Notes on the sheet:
Temperature Sensor+ EEPROM
"Swiftlet" Breakout PCB Copyright (c) 2015 by K. C. Lee
0.0

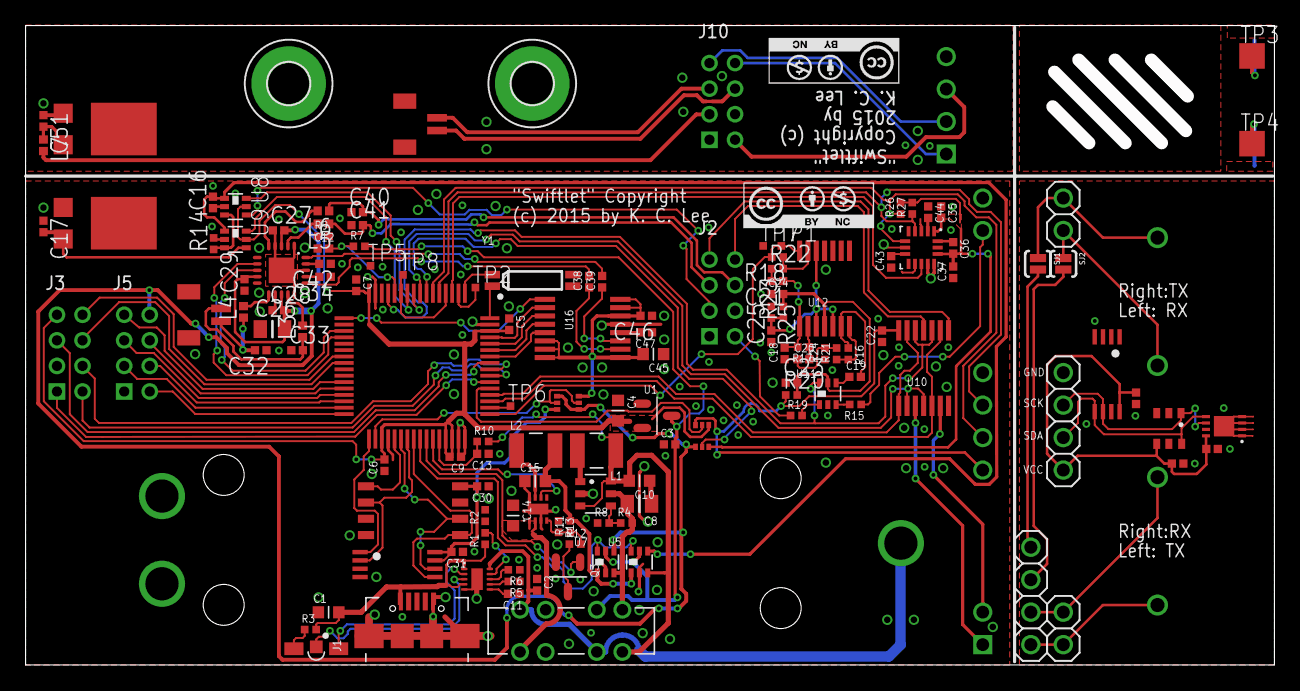
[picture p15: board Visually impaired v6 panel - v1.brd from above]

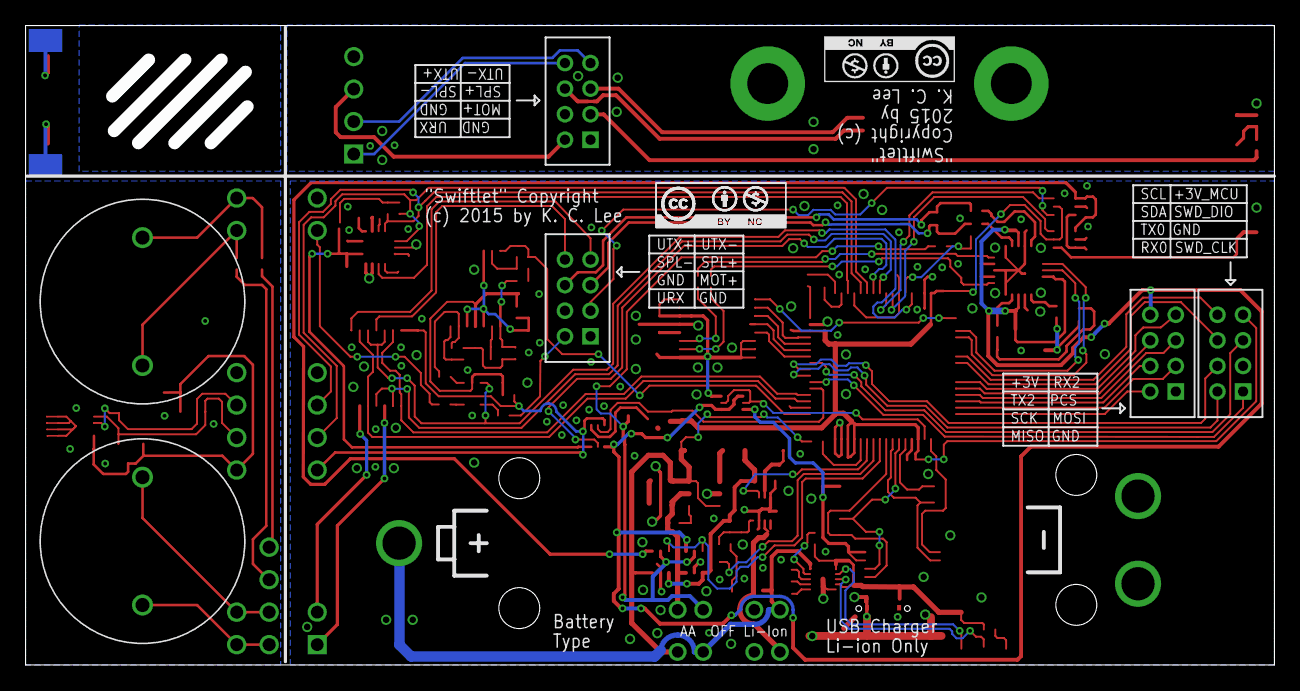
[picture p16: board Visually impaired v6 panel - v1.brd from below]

Board: 2 copper layers, 97.7 x 50.0 mm, 149 parts (6 on the bottom side), 128 nets.

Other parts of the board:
U$2, U$4, U$6: CC100%; CC-100

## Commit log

2015-07-25 Added printables
2015-09-11 Minor bug fixes - opamp swap & value changes
    [Visually impaired v6 panel - v1.brd, Visually impaired v6 panel - v1.sch]
2015-09-11 Rel 0.1 directory organization
    [Visually impaired v6 panel - v1.brd, Visually impaired v6 panel - v1.sch]
2015-09-12 Components consolidation & OM
    [Visually impaired v6 panel - v1.brd, Visually impaired v6 panel - v1.sch, Visually impaired v6 panel - v1_ListByValues.csv]
2015-09-21 Add sonar samples

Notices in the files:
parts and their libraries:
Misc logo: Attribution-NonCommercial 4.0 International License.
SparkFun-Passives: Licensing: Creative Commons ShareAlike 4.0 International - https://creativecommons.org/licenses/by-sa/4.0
